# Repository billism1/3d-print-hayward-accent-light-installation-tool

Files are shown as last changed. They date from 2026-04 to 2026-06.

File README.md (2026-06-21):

# 3D-Printed Accent Light Installation & Removal Tool: Compatible with Hayward® ColorLogic® 160 / 320

> **Disclaimer:** Independent, non-commercial project. **Not affiliated with, authorized, sponsored, or endorsed by Hayward Industries, Inc.** The names "Hayward," "ColorLogic," and "SP0536CTOOL" are used only to identify the products this tool is compatible with (nominative fair use). Hayward® and ColorLogic® are trademarks of Hayward Industries, Inc.; all trademarks are the property of their respective owners.

An independently designed, 3D-printable tool that is a **compatible alternative to** the **SP0536CTOOL**, the manufacturer's installation and removal tool for **Hayward® ColorLogic® 160 and 320 accent lights**. The design was created by measuring my own light fixture, not from any manufacturer drawings or CAD.

📦 **[View, download, or print on MakerWorld](https://makerworld.com/en/models/2957577-hayward-colorlogic-light-install-removal-tool)**

## Why This Exists

The original SP0536CTOOL broke during a light removal in my pool, and I didn't want to wait for a replacement. Rather than being stuck, I designed and printed my own version. Nothing here is for sale. This repo contains the OpenSCAD source files and ready-to-print exports, shared for reference.

## The Finished Tool

### Finished Hand Tool (Separated Prongs, Epoxied)

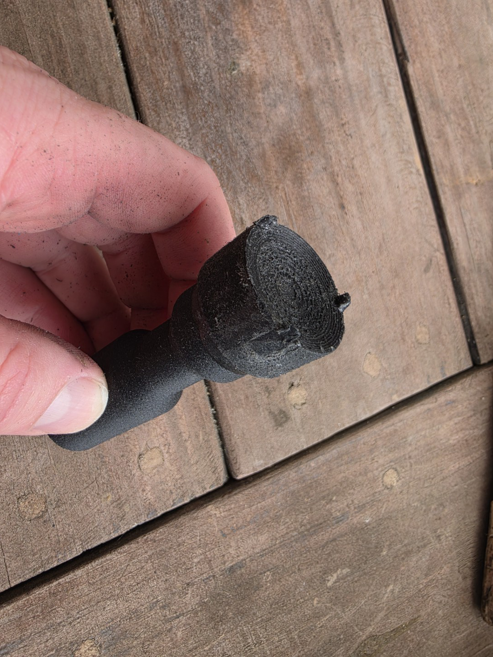
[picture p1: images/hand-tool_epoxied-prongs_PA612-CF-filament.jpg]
Hand tool with epoxied prongs — Fiberon PA612-CF


The final working version of the hand tool, printed in **Fiberon PA612-CF** nylon carbon fiber filament. The prongs were printed separately with layer lines running lengthwise, then epoxied into the designed slots on the end piece and left to cure overnight. This is the version that successfully survived the ColorLogic module replacement.

### 3D Printed Grip Collar

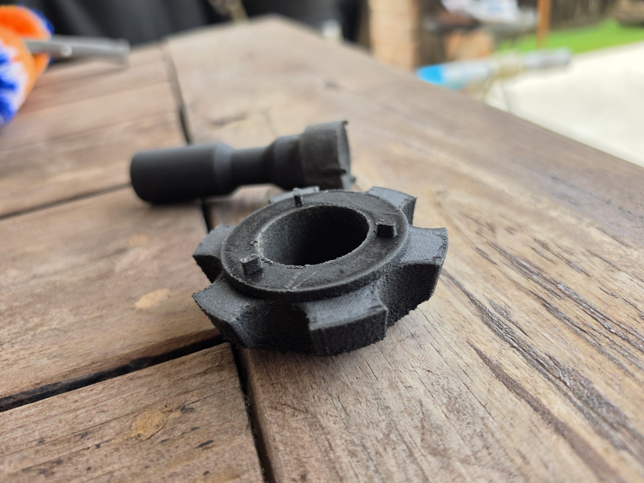
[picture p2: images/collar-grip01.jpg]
3D printed grip collar


The grip collar printed and in hand. Six gear-like teeth with semicircular cutouts give a positive grip for applying twist, and the tilted arced prongs on the top ledge engage the light's outer ring slots.

### Hand Tool in 3D Printed Collar Grip

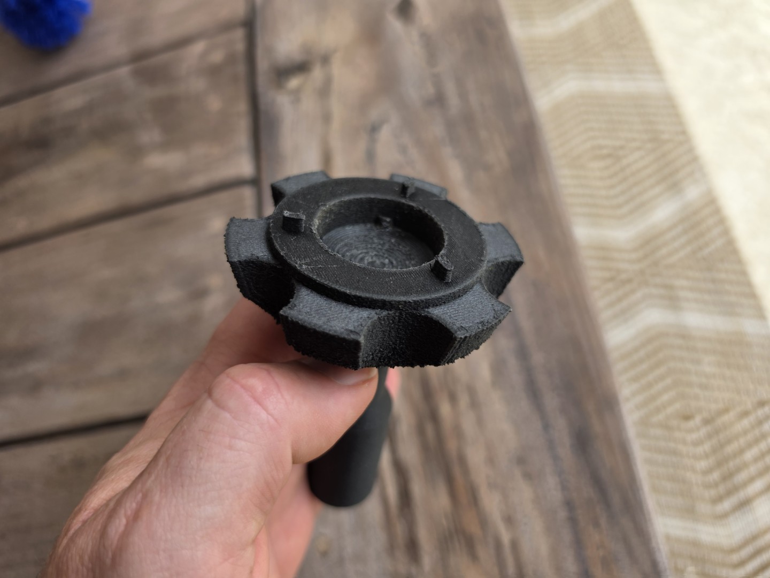
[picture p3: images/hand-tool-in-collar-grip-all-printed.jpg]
Hand tool seated in 3D printed collar grip


The fully 3D-printed assembly — the printed hand tool end piece seated inside the **printed grip collar** (both in Fiberon PA612-CF). This is the all-printed counterpart to the manufacturer-collar photo below, confirming the printed collar mates with the handle and end piece.

### 3D Printed End Piece in Manufacturer Collar Grip

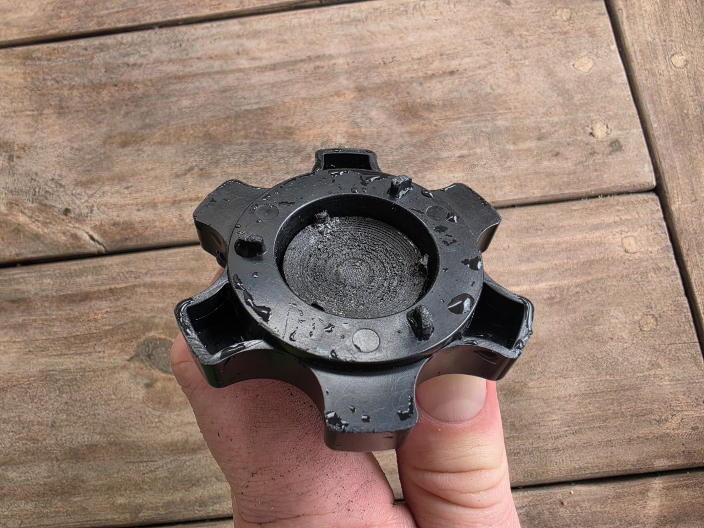
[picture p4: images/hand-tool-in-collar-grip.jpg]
Hand tool end piece seated in manufacturer collar grip


The 3D-printed end piece (printed in **Fiberon PA612-CF** filament) seated inside the **original manufacturer-supplied collar grip**, demonstrating compatibility. Since the OEM collar didn't break during use, only the handle and end piece needed to be reprinted.

## How the Tool Works

The Hayward ColorLogic accent lights mount into standard wall fittings (such as the **SP0537** or **SP0538**) using a **compression fitting**. The tool engages the light's outer ring and twists to expand or release the mounting ring inside the wall fitting.

The tool operates in two steps:

1. **Engagement** — The tool's end piece has a set of prongs ("little legs") that align with corresponding pins on the light's outer ring.
2. **Locking/Unlocking** — By twisting the tool, you rotate a fitting that compresses an internal washer. This causes the mounting ring to expand (or contract) and lock securely into (or release from) the wall fitting.

The tool consists of two main components: the **handle** (with an interlocking end piece) and the **grip collar**.

## Light Module Reference

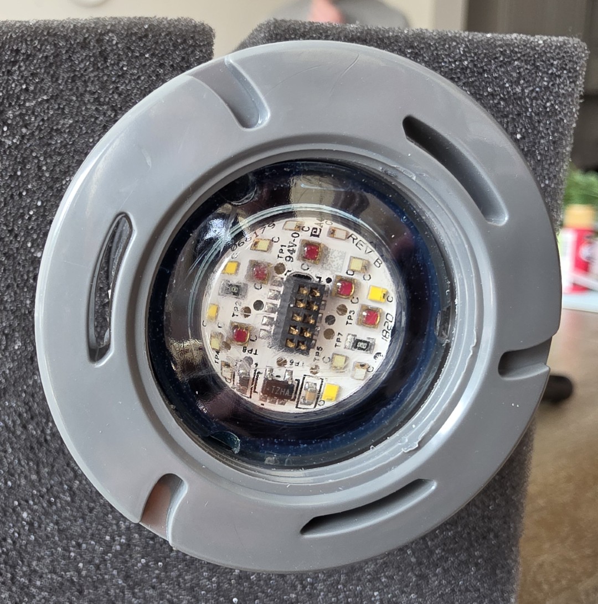
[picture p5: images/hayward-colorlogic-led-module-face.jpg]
Hayward ColorLogic LED module face


The face of a Hayward ColorLogic LED accent light module. The light has two concentric parts that the tool engages — the clear glass lens dome in the center (covering the LED board) and the gray plastic mounting ring around it. Two sets of slots are used:

- **Glass lens notches (3×)** — Cut into the clear glass lens dome surrounding the LED board, not the gray ring. The tool's end piece sits over the convex lens and its three prongs drop into these notches.
- **Gray ring slots (3×, short curved)** — Located on the outer gray mounting ring, these short curved slots are where the **grip collar prongs** engage. The collar sits over the gray ring and its tilted arced prongs seat into these slots to provide the twist leverage for locking/unlocking the light.

## Design Renders

### Handle with End Piece (Standard — Integrated Prongs)

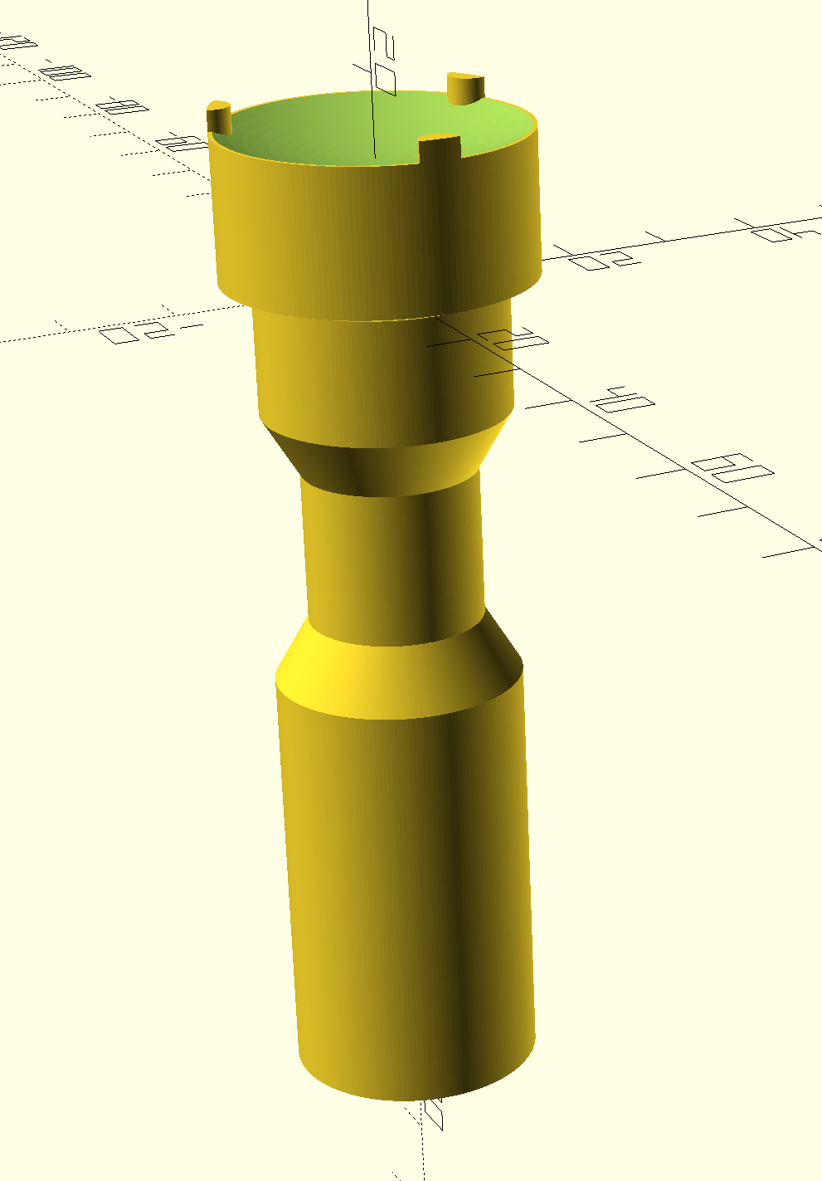
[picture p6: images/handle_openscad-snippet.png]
Handle with end piece — standard model


The handle and end piece shown as a single assembly. The concave dish on top cradles the light fixture, and three integrated prongs extend from the disc edge to engage the light's outer ring. The handle features a narrowed neck section for ergonomic grip.

### Handle with End Piece (Separate Components)

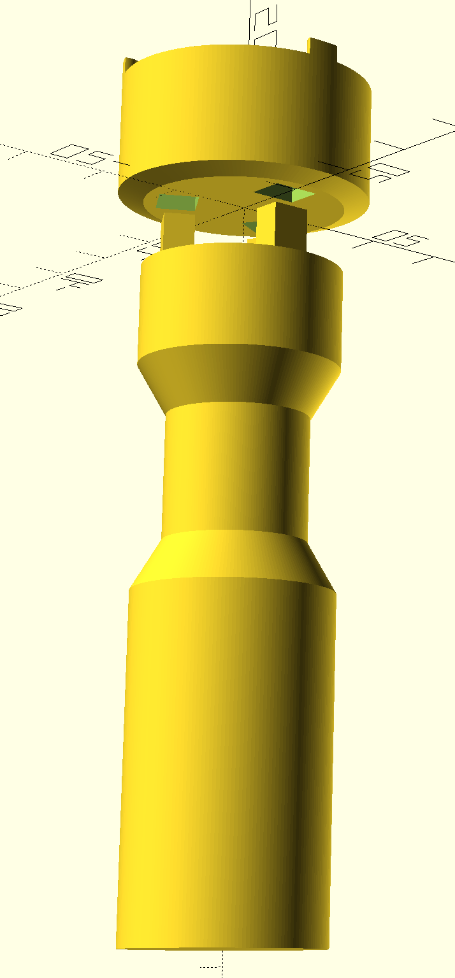
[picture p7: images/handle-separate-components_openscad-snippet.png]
Handle and end piece — separate components


The handle and end piece shown as separate printable parts. The interlocking tab system between the handle top and the disc underside is visible. The prongs here are still integrated into the end piece.

### Handle with End Piece (Separated Prongs Variant)

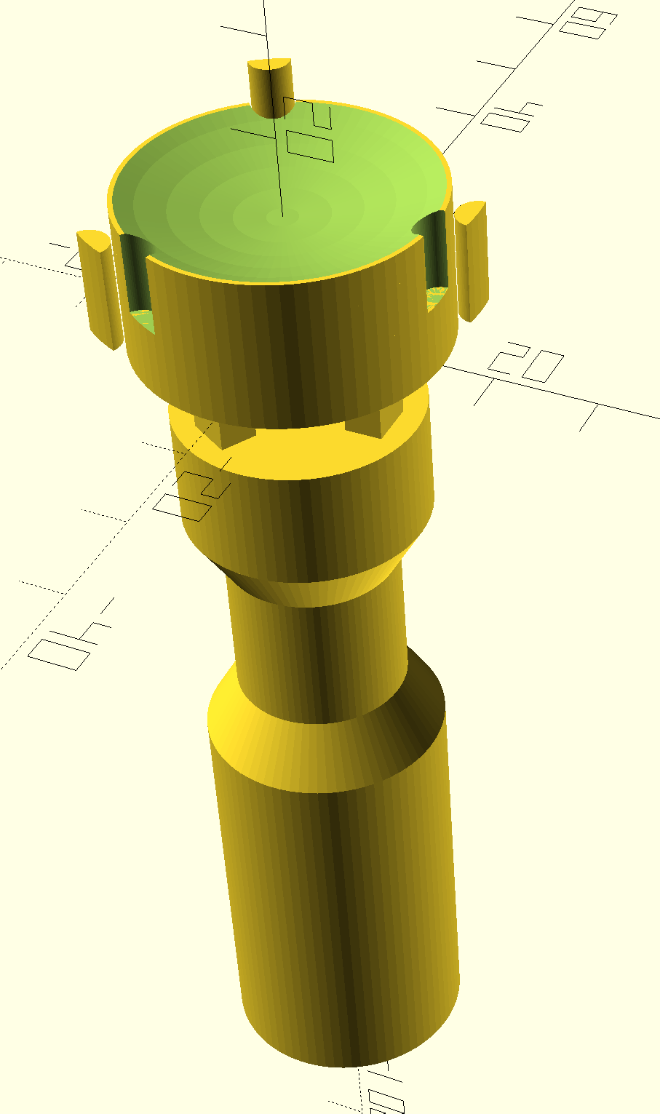
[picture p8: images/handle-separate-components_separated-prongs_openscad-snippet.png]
Handle and end piece — separated prongs variant


The improved separated prongs design. The end piece has three prong slots cut into it, and the individual prongs are printed separately alongside. This allows the prongs to be printed with layer lines running along their length for maximum inter-layer tensile strength, then epoxied into the slots.

### Grip Collar

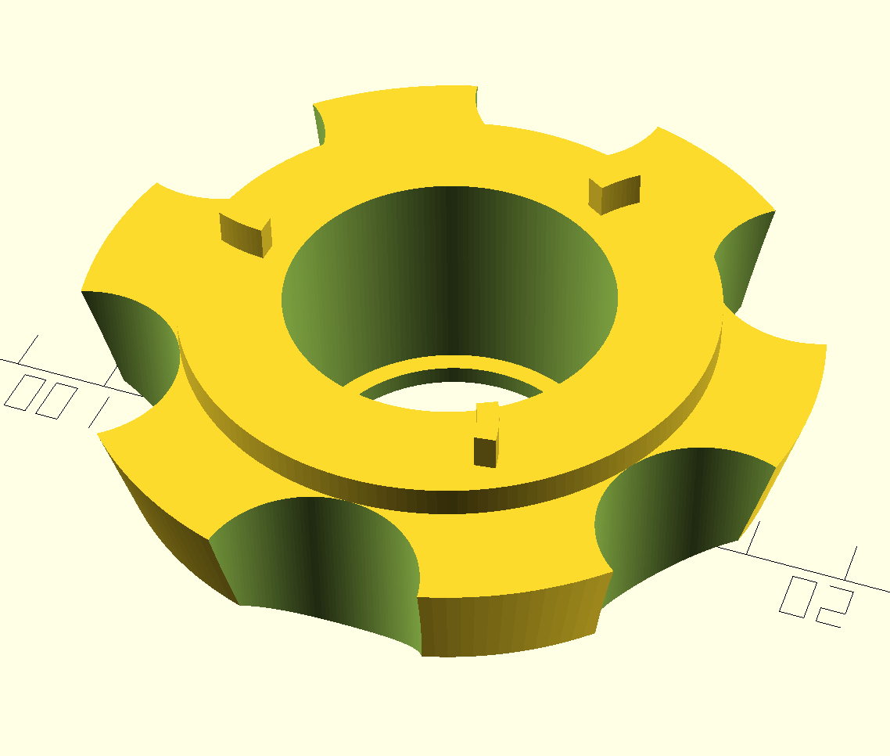
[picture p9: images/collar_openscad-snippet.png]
Grip collar


The grip collar viewed from above. Features six gear-like teeth with semicircular cutouts for hand grip, a prong ledge ring on top with three tilted arced prongs, and a retention lip on the bottom inside edge.

## Design Variants

### Standard Model (`hayward-accent-light-installation-tool.scad`)

The original design where the prongs are printed as part of the end piece. This is a simpler assembly but suffers from a critical weakness — the prongs are prone to snapping off due to weak **inter-layer tensile strength**. Because the prongs are small features extending from the disc, FDM layer lines run perpendicular to the prong length. Forces during installation/removal try to pull layers apart (delamination), which is the weakest failure mode in FDM printing.

### Separated Prongs Model (`hayward-accent-light-installation-tool_prongs-separated.scad`)

An improved design where the prongs are **printed as separate pieces** with layer lines running along their length (longitudinally). This orients the strong axis of each layer in the direction of load, dramatically improving **inter-layer tensile strength** and resistance to delamination. The prongs are then bonded into slots in the end piece with **epoxy** (cured overnight). Some light sanding of excess epoxy may be needed after curing.

## Printing Experience & Material Testing

All prints were done on a **Bambu Lab P1S**.

| Attempt | Model | Filament | Result |
|---|---|---|---|
| 1 | Standard (integrated prongs) | ASA (similar to ABS) | **Failed** — prongs snapped off very easily |
| 2 | Standard (integrated prongs) | Nylon Carbon Fiber (**Fiberon PA612-CF**) | Significantly stronger, but still managed to break a prong during use |
| 3 | Separated prongs | Fiberon PA612-CF + epoxy assembly | **Success** — prongs oriented with layer lines lengthwise held up to the torque required for light installation/removal |

### Key Takeaway

Printing small structural features like prongs **separately** and orienting them so that layer lines run parallel to the load direction provides far superior strength compared to printing them in-place. Even a high-performance filament like Nylon CF couldn't overcome the inherent inter-layer weakness of FDM when the prongs were printed as part of the larger piece.

## Assembly Notes (Separated Prongs Model)

1. Print the end piece and individual prongs separately.
2. Apply epoxy to the prong slots and insert the prongs.
3. Allow the epoxy to cure overnight.
4. Sand off any excess epoxy.

## TODO

- [ ] **Grip collar: separated prongs variant** — The grip collar also has prongs on its ledge that could benefit from the same separated-prong treatment for added strength. I didn't break the collar during my testing (only the end piece prongs failed), so this variant hasn't been designed yet. It is likely needed for long-term durability.

## Repository Structure

```
src/
  hayward-accent-light-installation-tool.scad              # Standard model (handle, end piece, grip collar)
  hayward-accent-light-installation-tool_prongs-separated.scad  # Separated prongs variant (end piece + handle)

publication/
  hayward-accent-light-installation-tool.3mf               # Bambu Lab 3MF project file
  hayward-accent-light-installation-tool_collar.stl         # Grip collar
  hayward-accent-light-installation-tool_end.stl            # End piece (standard, integrated prongs)
  hayward-accent-light-installation-tool_end_prong.stl      # Individual prong for separated model
  hayward-accent-light-installation-tool_end_with_prong_slots.stl  # End piece with prong slots
  hayward-accent-light-installation-tool_handle.stl         # Handle
  hayward-accent-light-installation-tool_handle_short.stl   # Short handle variant
  hayward-accent-light-installation-tool_one_peice.stl      # One-piece combined end piece + handle
```

## Compatible Lights & Fittings

- **Lights:** Hayward ColorLogic 160, ColorLogic 320 accent lights
- **Wall Fittings:** Hayward SP0537, SP0538 (1.5" female pipe thread)
- **OEM Tool:** Hayward SP0536CTOOL

## License

This is a personal project shared for reference under the [MIT License](LICENSE). Use at your own risk. Pool equipment installation involves water-tight seals and electrical components, so verify fit and function before relying on a 3D-printed tool for permanent installations.

See [LICENSE](LICENSE) for the full trademark notice and liability disclaimer.

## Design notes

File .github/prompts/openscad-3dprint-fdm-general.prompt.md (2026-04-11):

# OpenSCAD – General FDM 3D Printing Prompt

> Use this prompt for any OpenSCAD work targeting FDM (Fused Deposition Modelling) printers.

## Language Notes

OpenSCAD is a **functional CSG modelling language**, not a general-purpose programming language.

Key differences from typical languages:
- **No mutable variables** — all values are computed at parse time
- **No loops with side effects** — use `for()` as a geometric generator, not a control flow loop
- **Modules produce geometry**, not return values
- **`difference()`, `union()`, `intersection()`** are the core boolean CSG operations
- **`hull()`** creates the convex hull of its children — commonly used for fillets and smooth transitions
- **`translate()`, `rotate()`, `scale()`** are transforms applied to children
- **`$fn`** controls facet count (smoothness of curves)
- **`children()`** lets a module operate on geometry passed to it
- **`let()`** introduces named intermediate values inside expressions
- **`each`** flattens nested lists in list comprehensions

## FDM Design Principles

### Orientation matters
- The **flat, largest face should sit on the build plate** whenever possible.
- Minimise the need for support material by avoiding large unsupported overhangs.
- Vertical cylindrical holes print well; horizontal ones may need tear-drop or bridging profiles.

### Strength considerations
- **Layer lines are weakest in tension along Z.** Design load-bearing features so forces act across (XY) rather than between layers.
- Add fillets at the base of vertical features to distribute stress and reduce stress-risers.
- Prefer rounded transitions over sharp internal corners to avoid stress concentration.

### Printability guidelines
- Avoid very thin walls (< 2 × nozzle diameter). Typical minimum wall thickness: **0.8–1.2 mm** for a 0.4 mm nozzle.
- Bridging spans should stay under **~50 mm** without support.
- Overhangs up to **~45°** from vertical generally print without support; steeper angles may need chamfers or supports.
- Design snap-fits and living hinges with grain direction (layer orientation) in mind.

## Common Patterns

### Rounded rectangle (cube with round XY edges)
```openscad
module rounded_rect(size, r) {
    hull() {
        for (x = [r, size.x - r], y = [r, size.y - r])
            translate([x, y, 0])
                cylinder(r = r, h = size.z);
    }
}
```

### Fillet at base of a vertical feature
```openscad
module base_fillet(r, h) {
    difference() {
        cube([r, r, h]);
        translate([r, r, -0.01])
            cylinder(r = r, h = h + 0.02);
    }
}
```

### Chamfered hole (countersink / printer-friendly top)
```openscad
module chamfered_hole(d, h, chamfer = 0.6) {
    union() {
        cylinder(d = d, h = h);
        translate([0, 0, h - chamfer])
            cylinder(d1 = d, d2 = d + 2 * chamfer, h = chamfer + 0.01);
    }
}
```

### Shell / hollow box
```openscad
module shell(outer, wall) {
    difference() {
        cube(outer);
        translate([wall, wall, wall])
            cube([outer.x - 2*wall, outer.y - 2*wall, outer.z]);
    }
}
```

### Slot (elongated hole)
```openscad
module slot(length, d, h) {
    hull() {
        cylinder(d = d, h = h);
        translate([length, 0, 0])
            cylinder(d = d, h = h);
    }
}
```

### Counterbore hole
```openscad
module counterbore_hole(d_through, d_head, h_total, h_head) {
    union() {
        cylinder(d = d_through, h = h_total + 0.01);
        translate([0, 0, h_total - h_head])
            cylinder(d = d_head, h = h_head + 0.01);
    }
}
```

### Text / label emboss or deboss
```openscad
// Debossed (engraved) text on top surface
module debossed_label(txt, size, depth, font = "Liberation Sans:style=Bold") {
    translate([0, 0, -depth])
        linear_extrude(depth + 0.01)
            text(txt, size = size, font = font, halign = "center", valign = "center");
}
```

### Circular pattern (polar array)
```openscad
module polar_array(n, r) {
    for (i = [0 : n - 1])
        rotate([0, 0, i * 360 / n])
            translate([r, 0, 0])
                children();
}
```

## Tolerances for FDM 3D Printing

| Fit Type | Tolerance | Example |
|---|---|---|
| Press-fit (tight interference) | +0.1–0.2 mm on ID | `insert_od + 0.15` |
| Snug / sliding fit | +0.2–0.4 mm | `shaft_d + 0.3` |
| Loose / clearance fit | +0.5–1.0 mm | `cable_d + 0.6` |
| Screw through-hole | +0.3–0.5 mm | `M4 → 4.4 mm hole` |
| Self-threading (screw into plastic) | ~85% of nominal | `M4 → 3.4 mm hole` |
| Mating flat surfaces (stacking) | +0.2 mm per axis | offset to prevent binding |
| Lid / cap fit | +0.3–0.5 mm radial clearance | on diameter |

## Recommended `$fn` Values

| Feature | `$fn` | Notes |
|---|---|---|
| Small holes (< 6 mm) | 24–32 | Keeps file size small, holes still round |
| Medium cylinders (6–30 mm) | 48–64 | Good visual smoothness |
| Large curves / decorative | 96–128 | For visible surfaces |
| Hex shapes | 6 | `cylinder(..., $fn=6)` gives a hexagon |
| Quick preview / development | 16–24 | Faster render while iterating |
| Final export | 64–128 | Use higher values for production STL |

## CSG Best Practices

- Always extend cut volumes by **0.01 mm** (epsilon) beyond the surface to avoid z-fighting / coincident faces.
- Keep geometry **manifold** — no zero-thickness walls, no self-intersecting volumes.
- Use `render()` sparingly; it forces CGAL evaluation and slows preview.
- Name modules descriptively (e.g., `mounting_tab()`, `drain_slot()`) and parametrise dimensions at the top of the file.
- Group related constants together and comment units: `wall = 2.5; // mm`.
- Use `assert()` to guard against invalid parameter combinations.

## File Organisation

```
// 1. Constants & parameters
// 2. Derived dimensions
// 3. Helper / utility modules
// 4. Component modules
// 5. Assembly (top-level geometry)
```

Keep the top-level geometry at the **bottom** of the file so that reading top-to-bottom flows from parameters → helpers → final shape.

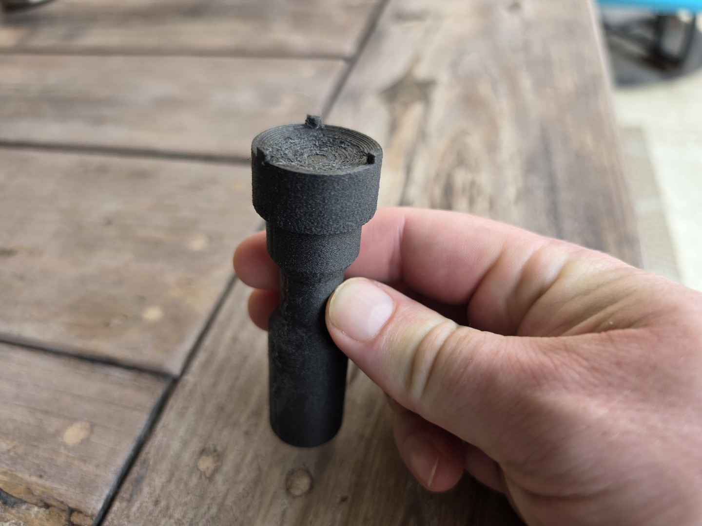
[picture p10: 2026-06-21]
images/hand-tool_integrated-prongs_PA612-CF-filament.jpg

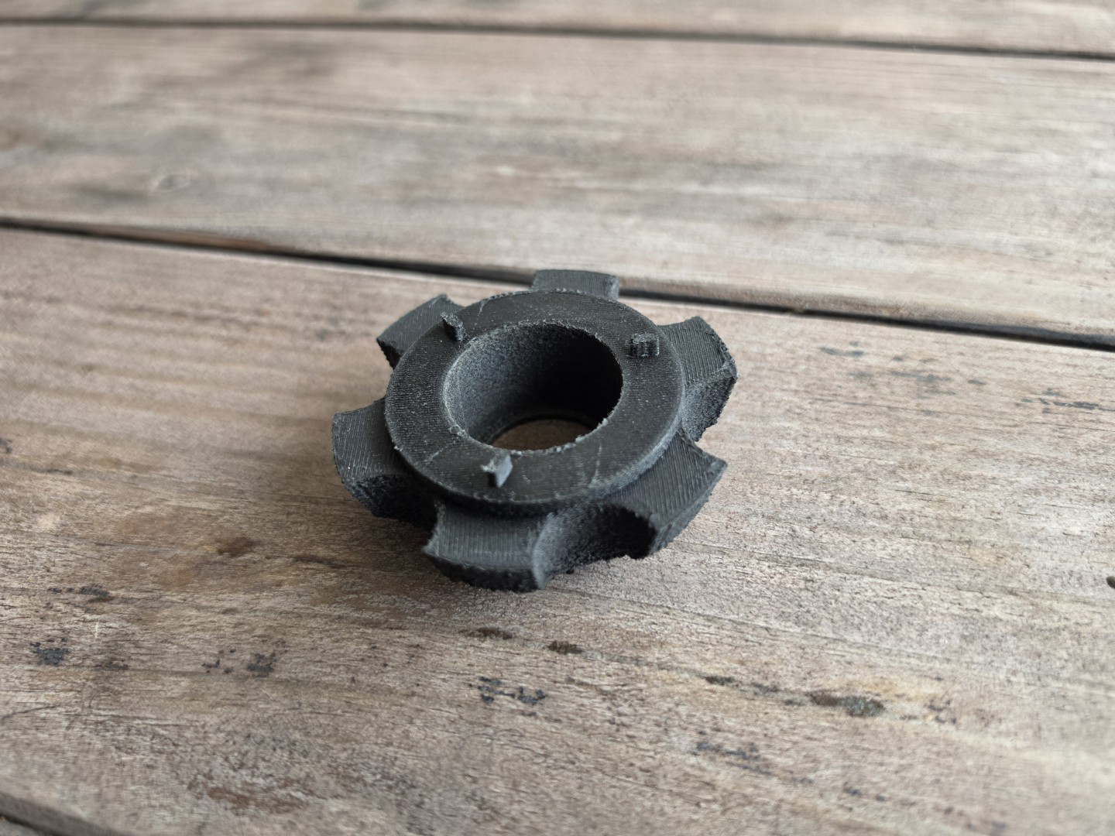
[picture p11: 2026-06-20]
images/collar-grip02.jpg

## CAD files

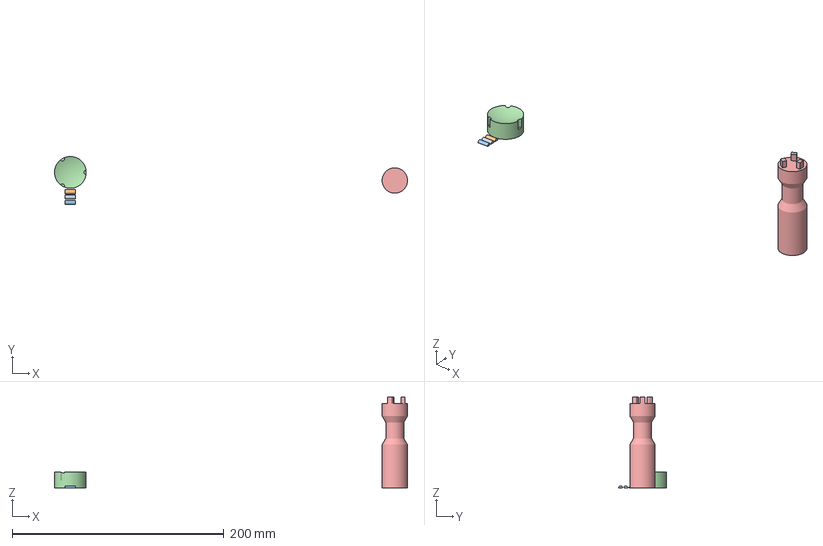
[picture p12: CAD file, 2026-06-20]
publication/hayward-accent-light-installation-tool_separated-prongs.3mf
333.8 x 45.4 x 86.0 mm
hayward-accent-light-installation-tool_end_prong.stl x 3
hayward-accent-light-installation-tool_end_with_prong_slots.stl
hayward-accent-light-installation-tool_handle.stl

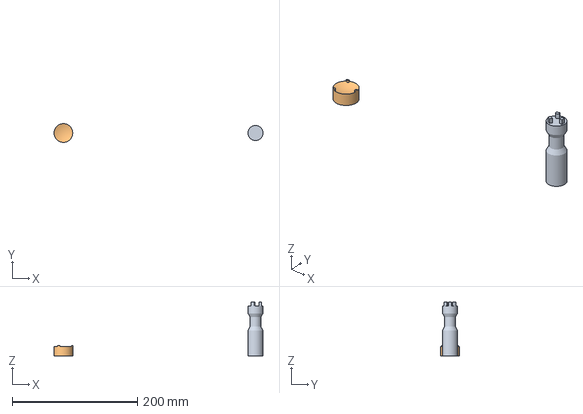
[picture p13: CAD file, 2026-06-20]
publication/hayward-accent-light-installation-tool_integrated-prongs.3mf
334.2 x 30.0 x 86.0 mm
hayward-accent-light-installation-tool_handle.stl
hayward-accent-light-installation-tool_end.stl

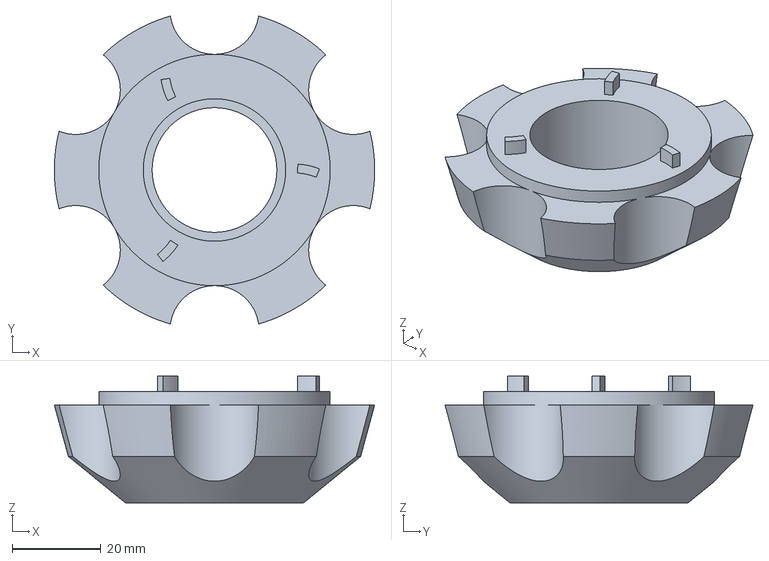
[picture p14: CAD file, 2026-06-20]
publication/hayward-accent-light-installation-tool_collar-grip.3mf
72.0 x 69.2 x 28.5 mm

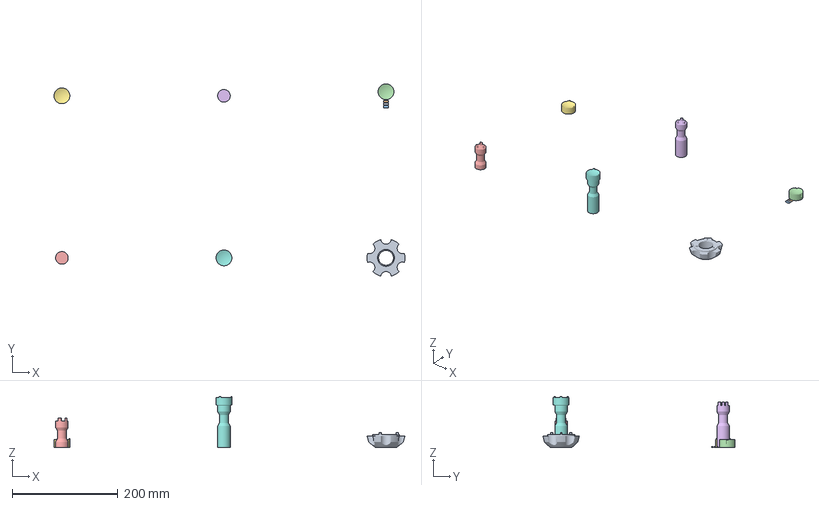
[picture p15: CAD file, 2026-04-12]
publication/hayward-accent-light-installation-tool.3mf
665.4 x 364.5 x 97.0 mm
hayward-accent-light-installation-tool_end_prong.stl x 3
hayward-accent-light-installation-tool_end_with_prong_slots.stl
hayward-accent-light-installation-tool_handle_short.stl
hayward-accent-light-installation-tool_handle.stl
hayward-accent-light-installation-tool_end.stl
hayward-accent-light-installation-tool_one_peice.stl
hayward-accent-light-installation-tool_collar.stl

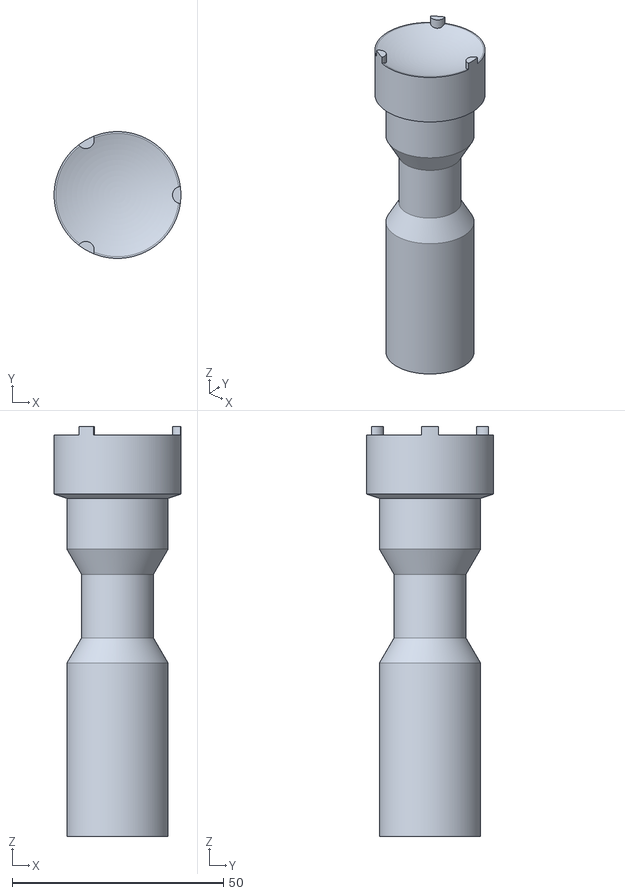
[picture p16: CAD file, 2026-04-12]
publication/hayward-accent-light-installation-tool_one_peice.stl
30.0 x 30.0 x 97.0

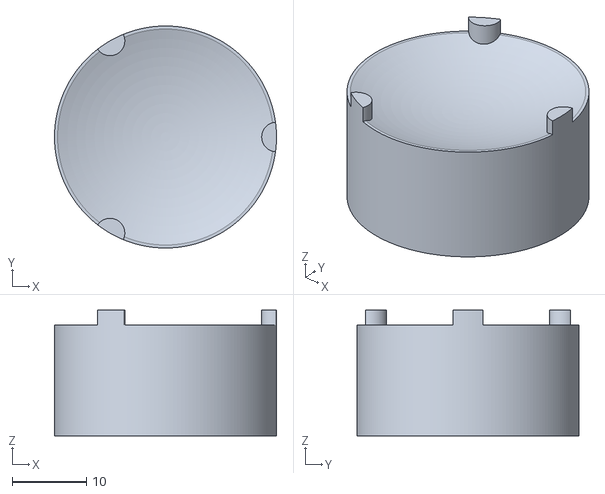
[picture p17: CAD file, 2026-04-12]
publication/hayward-accent-light-installation-tool_end.stl
30.0 x 30.0 x 17.0

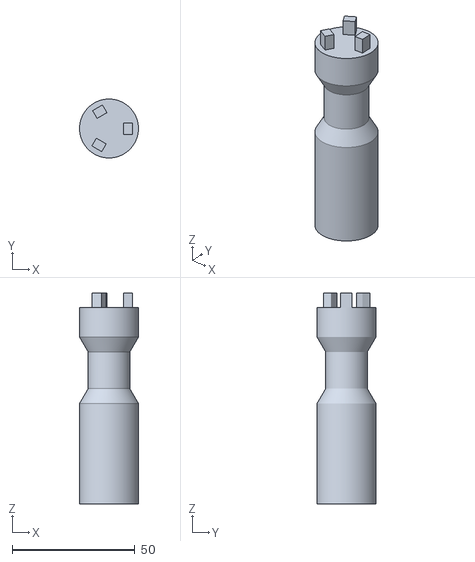
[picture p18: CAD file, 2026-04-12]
publication/hayward-accent-light-installation-tool_handle.stl
24.0 x 24.0 x 86.0

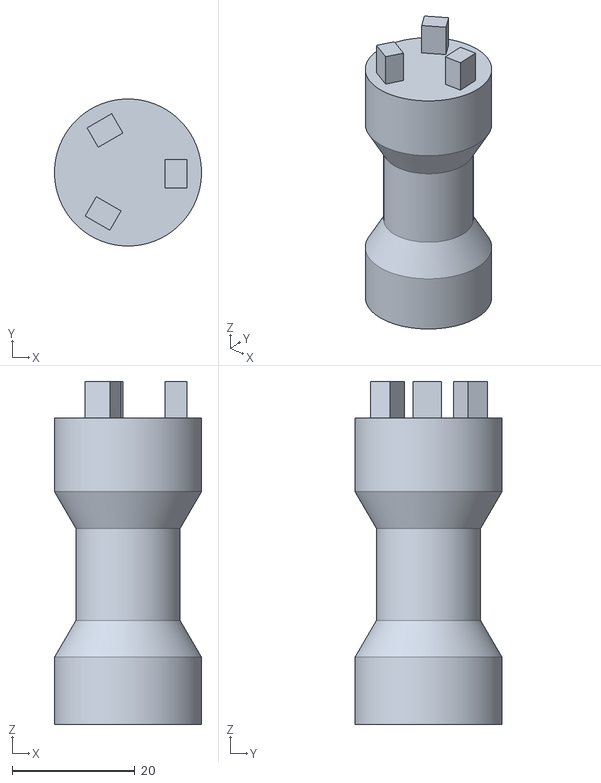
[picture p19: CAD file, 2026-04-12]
publication/hayward-accent-light-installation-tool_handle_short.stl
24.0 x 24.0 x 56.0

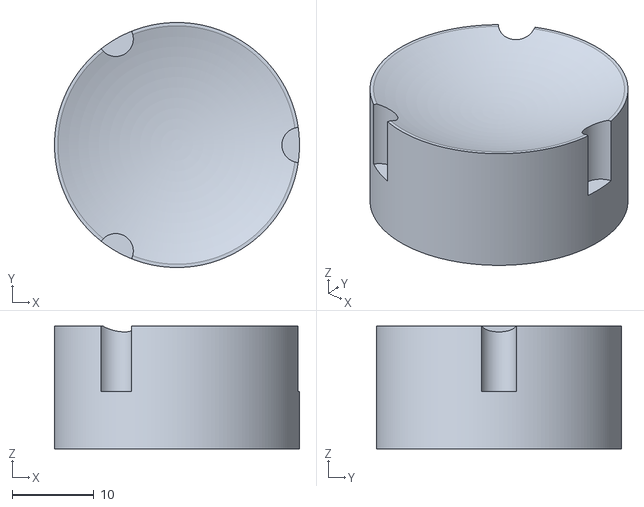
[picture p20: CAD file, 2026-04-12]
publication/hayward-accent-light-installation-tool_end_with_prong_slots.stl
30.0 x 30.0 x 15.0

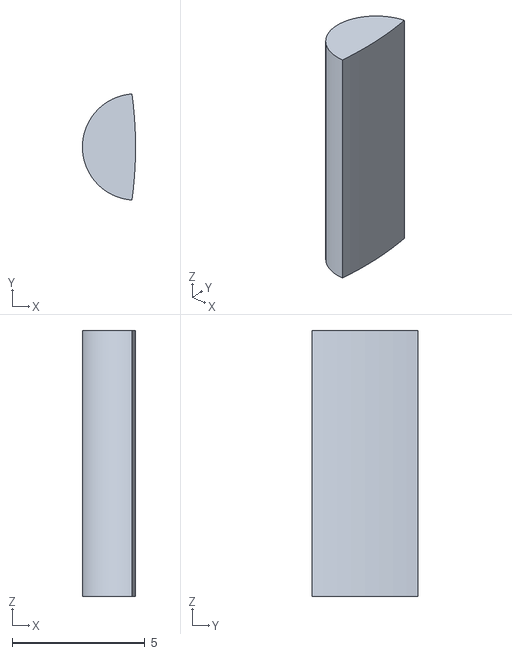
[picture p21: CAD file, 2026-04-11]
publication/hayward-accent-light-installation-tool_end_prong.stl
2.00 x 3.99 x 10.0

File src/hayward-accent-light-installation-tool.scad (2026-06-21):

// ============================================================
// Accent Light Installation Tool (End Piece), compatible with Hayward ColorLogic 160/320
// Independent, non-commercial project. Not affiliated with Hayward Industries, Inc.
// ============================================================

// ----- Constants & Parameters -----
disc_diameter   = 30;     // mm – outer diameter of the circular end
disc_thickness  = 15;     // mm – depth (Z) of the flat disc

prong_height    = 2;      // mm – how far prongs extend above the disc
prong_arc_len   = 4;    // mm – arc length of each prong along circumference
prong_count     = 3;

// Concave dish on top of disc (to cradle convex light fixture)
dish_depth      = 3;      // mm – how deep the concavity is

// Render toggles
render_end_piece  = true;
render_handle     = true;
render_grip_collar = true;
render_combined   = false;  // true = union end piece + handle as one solid object

// Handle parameters
handle_diameter = 24;     // mm
handle_length   = 80;     // mm
handle_gap      = 2;      // mm – visual gap between handle and disc

// Handle neck parameters
neck_start      = 12;     // mm – distance from top of handle to start of neck
neck_diameter   = 17;     // mm – narrowed diameter
neck_length     = 15;     // mm – length of the narrow section
neck_taper      = 6;      // mm – length of each conical transition

// Grip collar parameters
collar_inner_diameter  = 32;     // mm – inside diameter (end piece sits inside)
collar_base_thickness  = 10;     // mm – base ring wall thickness at top
collar_base_thickness_bottom = 4; // mm – base ring wall thickness at bottom
collar_tooth_thickness = 10;     // mm – additional thickness for gear-tooth region
collar_height          = 22;     // mm – height when printed flat on bed
collar_tooth_count     = 6;      // number of gear-like grip teeth
collar_ledge_width     = 10;     // mm – radial width of the prong ledge ring on top
collar_ledge_height    = 3;      // mm – height the ledge extrudes above the collar
collar_tooth_taper_h   = 13;     // mm – height of 45° taper on bottom of teeth (= tooth thickness)

// Collar lip parameters (retention lip on bottom inside)
collar_lip_height      = 2;      // mm – height of the lip
collar_lip_thickness   = 2;      // mm – radial extent inward from inner diameter

// Collar prong parameters
collar_prong_height    = 3.5;    // mm – height of prongs above the ledge
collar_prong_thickness = 2;    // mm – wall thickness of each prong arc
collar_prong_count     = 3;      // number of prongs, evenly spaced
collar_prong_ring_od   = 30;     // mm – outer diameter of the hypothetical ring defining arc curvature
collar_prong_length    = 5;      // mm – radial length of each prong arc
collar_prong_tilt      = 12.5;     // degrees – clockwise tilt (outer end leads CW viewed from top)

// Interlocking tab parameters
tab_count       = 3;
tab_width       = 5;      // mm – width tangentially
tab_depth       = 4;      // mm – radial depth of each tab
tab_height      = 6;      // mm – how far tabs protrude into the disc
tab_radial_pos  = 8;      // mm – distance from center to tab center
tab_clearance   = render_combined ? 0.0 : 0.35;   // mm – press-fit tolerance per side (0 when combined)

// ----- Derived Dimensions -----
disc_radius     = disc_diameter / 2;
handle_radius   = handle_diameter / 2;
prong_arc_angle = (prong_arc_len / (PI * disc_diameter)) * 360; // degrees
eps             = 0.01;   // mm – tiny overlap to avoid z-fighting

// Slot dimensions (tab + clearance on each side)
slot_width      = tab_width + 2 * tab_clearance;
slot_depth      = tab_depth + 2 * tab_clearance;

// Grip collar derived dimensions
collar_inner_radius = collar_inner_diameter / 2;
collar_total_thickness = collar_base_thickness + collar_tooth_thickness;
collar_outer_radius = collar_inner_radius + collar_total_thickness;  // full outer radius including teeth
collar_base_outer_radius = collar_inner_radius + collar_base_thickness; // outer radius of base ring at top
collar_base_outer_radius_bottom = collar_inner_radius + collar_base_thickness_bottom; // outer radius of base ring at bottom
collar_outer_radius_bottom = collar_base_outer_radius_bottom + collar_tooth_thickness; // full outer radius at bottom
collar_cutout_radius = collar_tooth_thickness;  // radius of each semicircular cutout

// Collar prong derived dimensions
collar_prong_ring_or = collar_prong_ring_od / 2;
collar_prong_ring_ir = collar_prong_ring_or - collar_prong_thickness;
// Radial center of the ledge, where prongs sit
collar_prong_center_r = collar_inner_radius + collar_ledge_width / 2;
// Arc angle derived from the hypothetical ring curvature and desired prong length
collar_prong_arc_deg = (collar_prong_length / collar_prong_ring_or) * (180 / PI);

// ----- Quality -----
$fn = 80;

// ----- Component Modules -----

disc_taper_height = 1;    // mm – height of conical taper at bottom of disc

module disc() {
    // Bottom cone: tapers from handle_diameter up to disc_diameter
    cylinder(d1 = handle_diameter, d2 = disc_diameter, h = disc_taper_height);
    // Remaining straight cylinder
    translate([0, 0, disc_taper_height])
        cylinder(d = disc_diameter, h = disc_thickness - disc_taper_height);
}

module prong() {
    prong_total_h = prong_height + dish_depth + eps;
    half_arc = prong_arc_len / 2;

    // Lens shape from above: outer follows disc curvature, inner is convex toward center
    intersection() {
        // Cylinder centered on disc edge along +X
        translate([disc_radius, 0, 0])
            cylinder(r = half_arc, h = prong_total_h);
        // Clip to inside the disc radius
        cylinder(r = disc_radius, h = prong_total_h);
    }
}

module prongs() {
    for (i = [0 : prong_count - 1])
        rotate([0, 0, i * (360 / prong_count)])
            translate([0, 0, disc_thickness - dish_depth - eps])
                prong();
}

// Cutout slots in the bottom of the disc for the handle tabs
module disc_slots() {
    for (i = [0 : tab_count - 1])
        rotate([0, 0, i * (360 / tab_count)])
            translate([tab_radial_pos - slot_depth / 2,
                       -slot_width / 2,
                       -eps])
                cube([slot_depth, slot_width, tab_height + eps]);
}

// Spherical concave dish cut from the top of the disc
module dish_cutout() {
    // Sphere radius derived so that a cap of dish_depth has the disc's radius as chord
    dish_r = (disc_radius * disc_radius + dish_depth * dish_depth) / (2 * dish_depth) - 2;
    translate([0, 0, disc_thickness - dish_depth + dish_r])
        sphere(r = dish_r);
}

// The disc with slots and concave dish cut out
module end_piece() {
    difference() {
        disc();
        disc_slots();
        dish_cutout();
    }
    prongs();
}

// Tabs that protrude from the top of the handle
module handle_tabs() {
    for (i = [0 : tab_count - 1])
        rotate([0, 0, i * (360 / tab_count)])
            translate([tab_radial_pos - tab_depth / 2,
                       -tab_width / 2,
                       handle_length])
                cube([tab_depth - tab_clearance, tab_width - tab_clearance, tab_height]);
}

module handle() {
    neck_bottom = handle_length - neck_start - neck_taper - neck_length - neck_taper;
    // Top section: full diameter
    translate([0, 0, handle_length - neck_start])
        cylinder(d = handle_diameter, h = neck_start);
    // Upper taper: handle_diameter -> neck_diameter
    translate([0, 0, handle_length - neck_start - neck_taper])
        cylinder(d1 = neck_diameter, d2 = handle_diameter, h = neck_taper);
    // Narrow neck section
    translate([0, 0, handle_length - neck_start - neck_taper - neck_length])
        cylinder(d = neck_diameter, h = neck_length);
    // Lower taper: handle_diameter -> neck_diameter
    translate([0, 0, neck_bottom])
        cylinder(d1 = handle_diameter, d2 = neck_diameter, h = neck_taper);
    // Bottom section: full diameter
    cylinder(d = handle_diameter, h = neck_bottom);
    handle_tabs();
}

// ----- Grip Collar Module -----
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

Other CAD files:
publication/hayward-accent-light-installation-tool_collar.stl
src/hayward-accent-light-installation-tool_prongs-separated.scad

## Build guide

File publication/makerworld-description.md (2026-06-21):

# 3D-Printed Accent Light Installation & Removal Tool: Compatible with Hayward ColorLogic

An independently designed 3D-printable alternative, compatible with the Hayward ColorLogic light system (replaces the function of the SP0536CTOOL).

> **Disclaimer:** Independent, non-commercial project. **Not affiliated with, authorized, sponsored, or endorsed by Hayward Industries, Inc.** The names "Hayward," "ColorLogic," and "SP0536CTOOL" are used only to identify the products this tool is compatible with (nominative fair use). Hayward® and ColorLogic® are trademarks of Hayward Industries, Inc.; all trademarks are the property of their respective owners.

> **Source & Documentation:** OpenSCAD source, photos, and full documentation: [github.com/billism1/3d-print-hayward-accent-light-installation-tool](https://github.com/billism1/3d-print-hayward-accent-light-installation-tool)

Yeah, so the manufacturer's tool for replacing ColorLogic accent lights broke mid-removal, with the light still in the wall. Could have ordered another one and waited. Instead I broke a few prototypes, reinforcing what I already know about FDM layer orientation: it actually matters for small pieces, and ended up with a tool that survived the job. I designed this from measuring my own light, not from any manufacturer drawings. Three print profiles below: two for the hand tool (pick by how much epoxy you feel like dealing with), plus a separate one for the grip collar if yours broke too. Realistically, almost nobody needs this. But if your tool broke and your light is still stuck in the wall, you are exactly the person I made it for. So hello to the few of you who stumble across this, probably years from now. Small club, glad you're here.

This is an independently designed, 3D-printable alternative to the **SP0536CTOOL**, the manufacturer's installation and removal tool for **Hayward ColorLogic 160 and 320** accent lights. Nothing here is for sale. The tool engages the light's outer ring and twists to expand or release the internal mounting ring inside a standard wall fitting (SP0537, SP0538).

## Three Print Profiles

Profiles 1 and 2 both print the **hand tool: the end piece *and* the handle**. The handle has extension pieces (tabs) that insert into matching slots in the underside of the end piece to hold the two together. I epoxied mine, but I also ran it *without* epoxying the handle to the end piece and it held up fine — the tabs alone keep them together. So epoxy on the handle joint is optional; glue it only if you want it permanent.

Profile 3 is the grip collar, broken out on its own because you may not need it. Print it only if your OEM collar didn't survive. Mine survived. I designed and printed one anyway. Two reasons: I can't leave a set half-finished, and your collar might not be as lucky as mine.

**Profile 1: Separated Prongs (Stronger, Recommended)**
The end piece prints with three prong slots. The three prongs print separately, lying flat on the bed so their layer lines run along their length. You epoxy the prongs into the slots. Stronger because the strong axis of each layer is now aligned with the torque, instead of fighting it across layer bonds. The handle prints separately and its tabs insert into the end piece (epoxy on that joint optional).

**Profile 2: Integrated Prongs (Simpler)**
The end piece prints as one part with the prongs as integrated features. Fewer pieces, no prong epoxy step, faster to assemble. The trade-off is the inter-layer weakness. Even Nylon CF couldn't fully overcome it in my testing. Fine for a one-time removal or a backup. If you just need to get the light out today, this is the fastest path. The handle still prints separately and its tabs insert into the end piece (epoxy on that joint optional).

**Profile 3: Grip Collar (Optional — Print Only If Needed, Or If You're Like Me)**
Just the grip collar, on its own. Six gear-style teeth for hand grip, a retention lip, and three tilted arced prongs that engage the outer ring slots on the light. Print this only if your OEM Hayward collar broke — the printed end piece drops into the original collar fine. My OEM collar was perfectly intact. I designed this one anyway. No regrets. Print it by itself or alongside Profile 1 or 2.

## What's Included

Long handle: separate part, epoxied to the underside of the end piece. Tab system aligns it; epoxy holds it.
End piece: two versions, one per profile (slotted vs. integrated).
Individual prong: three needed for Profile 1.
Grip collar: one piece. Skip printing it if your OEM collar survived; the 3D-printed end piece fits inside the original collar fine.

## Key Features

Designed for FDM strength. Profile 1 puts the prongs' layer lines along the load direction, where FDM is strong, instead of perpendicular, where it delaminates.
Interlocking handle joint: three tab-and-slot pairs align the handle to the end piece before you epoxy.
Concave dish on the end piece cradles the convex face of the light fixture.
Narrowed neck on the handle gives you something ergonomic to grip and twist.
Six-tooth grip collar: gear-style cutouts for hand grip, with a retention lip and three tilted arced prongs to engage the outer ring slots on the light.
OEM-compatible end piece fits inside the manufacturer-supplied collar if you only broke the handle.

## Print Tips

**Filament:** Print in something tough. My log:

Attempt 1: Integrated prongs in ASA. Prongs snapped almost immediately.
Attempt 2: Integrated prongs in **Fiberon PA612-CF** (Nylon CF). Stronger, but still broke a prong under twist torque.
Attempt 3: Separated prongs in **Fiberon PA612-CF** + epoxy. Held up to the full install/removal torque.

PLA is going to disappoint you. PETG or ABS *might* survive Profile 1. PA-CF or PA6-CF is the safer bet for either profile. All my prints were on a **Bambu Lab P1S**.

**Orientation:** The included files are already oriented for the right layer direction. The separated prongs print flat on the bed (longitudinal layer lines), and the slotted end piece prints with the dish facing up.

**Epoxy:** Two-part epoxy is fine (5-minute or slow-cure both work). Squeeze-out is normal. Wipe or sand it after cure.

## Assembly

**Profile 1 (Separated Prongs):**
1. Print the end piece (with prong slots), three prongs, and handle. Print the grip collar too (Profile 3) only if you need it.
2. Epoxy the prongs into the end piece slots. Cure overnight.
3. Insert the handle's tabs into the slots on the underside of the end piece. Epoxy here is optional — mine ran fine unglued. If gluing, cure overnight.
4. Light sand any squeeze-out.
5. Drop the end piece into the grip collar (printed or OEM). Go remove your light.

**Profile 2 (Integrated Prongs):**
1. Print the end piece and handle. Print the grip collar too (Profile 3) only if you need it.
2. Insert the handle's tabs into the slots on the underside of the end piece. Epoxy here is optional — mine ran fine unglued. If gluing, cure overnight.
3. Drop the end piece into the grip collar (printed or OEM). Go remove your light.

**Profile 3 (Grip Collar):**
1. Print the grip collar. Drop your end piece in and go.

## Compatibility

Lights: Hayward ColorLogic 160, ColorLogic 320
Wall fittings: Hayward SP0537, SP0538 (1.5" female pipe thread)
Replaces: Hayward SP0536CTOOL

## Notes

The grip collar has its own set of prongs and could probably benefit from the same separated-prong treatment, but mine didn't break, so I haven't designed that variant yet. Yes, I designed a whole replacement collar for a part that was working fine, and no, I will not be explaining the separated-prong variant I didn't make for the collar I didn't need. Eventually, maybe.

Pool equipment involves water-tight seals and electrical components. Verify fit before relying on this for anything permanent, and use at your own risk. If a prong shears mid-twist you'll know which profile you should have picked.

## Source & Documentation

OpenSCAD source, photos, and full documentation: [github.com/billism1/3d-print-hayward-accent-light-installation-tool](https://github.com/billism1/3d-print-hayward-accent-light-installation-tool)

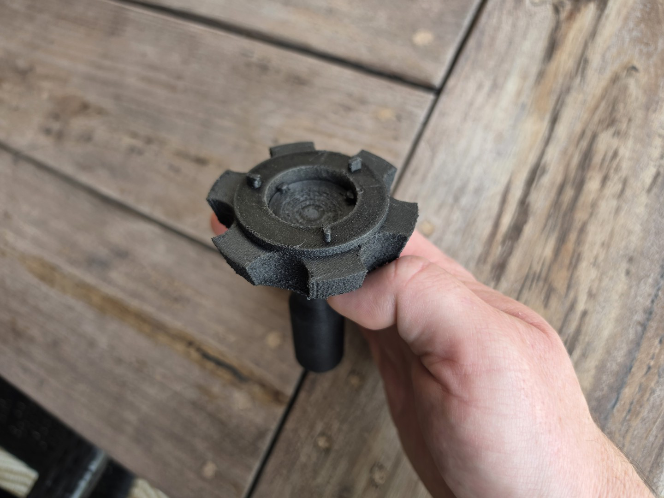
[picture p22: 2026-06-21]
images/hand-tool-integrated-prongs-in-collar-grip-all-printed.jpg

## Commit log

2026-04-11 Add OpenSCAD prompt and implementation for Hayward ColorLogic accent light installation tool
    [hayward-accent-light-installation-tool.scad]
2026-04-11 Update parameters for Hayward ColorLogic accent light installation tool: adjust disc thickness, prong height, and arc length; increase quality resolution.
    [hayward-accent-light-installation-tool.scad, hayward-accent-light-installation-tool_end.stl]
2026-04-11 Refactor Hayward ColorLogic accent light installation tool: update disc thickness, add handle and tab parameters, and implement end piece and handle modules for improved assembly.
    [hayward-accent-light-installation-tool.scad]
2026-04-11 Add handle module and render toggles for Hayward ColorLogic accent light installation tool
    [hayward-accent-light-installation-tool.scad, hayward-accent-light-installation-tool_end.stl, hayward-accent-light-installation-tool_handle.stl]
2026-04-11 Refactor handle module in Hayward ColorLogic accent light installation tool: adjust handle diameter, add neck parameters, and modify handle geometry for improved design.
    [hayward-accent-light-installation-tool.scad]
2026-04-11 Add 3D model files for Hayward ColorLogic accent light installation tool
    [hayward-accent-light-installation-tool.3mf, hayward-accent-light-installation-tool_end.stl, hayward-accent-light-installation-tool_handle.stl]
2026-04-11 Refactor end piece module in Hayward ColorLogic accent light installation tool: add concave dish cutout and adjust prong height calculation.
    [hayward-accent-light-installation-tool.scad, hayward-accent-light-installation-tool_end.stl]
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2026-04-11 Update disc diameter and enable handle rendering in accent light installation tool
    [hayward-accent-light-installation-tool.scad]
2026-04-11 Adjust prong arc length and implement lens shape for improved prong design in accent light installation tool
    [hayward-accent-light-installation-tool.scad]
2026-04-11 Adjust dish radius calculation in dish cutout module for improved fit of the end piece
    [hayward-accent-light-installation-tool.scad, hayward-accent-light-installation-tool_end.stl]
2026-04-11 Add new prong and handle modules to the Hayward ColorLogic accent light installation tool
    [hayward-accent-light-installation-tool_prongs-separated.scad]
2026-04-11 Enhance prong design by adding insertion depth and clearance parameters, and implement prong slots for improved fitting and printing.
    [hayward-accent-light-installation-tool_prongs-separated.scad]
2026-04-11 Reposition individual prongs for improved printing layout and add gap between prong and disc edge
    [hayward-accent-light-installation-tool_prongs-separated.scad]
2026-04-11 Update rendering options and improve dish cutout calculation for accent light tool
    [hayward-accent-light-installation-tool.3mf, hayward-accent-light-installation-tool.scad, hayward-accent-light-installation-tool_end.stl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]
2026-04-11 Enable rendering of handle and prongs in accent light installation tool, and reduce quality factor for improved performance
    [hayward-accent-light-installation-tool.scad, hayward-accent-light-installation-tool_prongs-separated.scad]
2026-04-11 Add handle short STL file and adjust handle length parameter to 50mm
    [hayward-accent-light-installation-tool.scad, hayward-accent-light-installation-tool_handle_short.stl]
2026-04-11 Update 3MF file for accent light installation tool with improved design features
    [hayward-accent-light-installation-tool.3mf]
2026-04-11 Update 3MF file for accent light installation tool with new design modifications
    [hayward-accent-light-installation-tool.3mf]
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2026-04-11 Update grip collar height and add taper for improved fit and support
    [hayward-accent-light-installation-tool.scad]
2026-04-11 Add collar prong parameters and adjust tab clearance for improved fit
    [hayward-accent-light-installation-tool.scad, hayward-accent-light-installation-tool_handle.stl, hayward-accent-light-installation-tool_handle_short.stl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]
2026-04-11 Update 3MF file for accent light installation tool with latest design changes
    [hayward-accent-light-installation-tool.3mf]
2026-04-12 Adjust tab clearance for improved press-fit tolerance in handle module
    [hayward-accent-light-installation-tool.scad]
2026-04-12 Update STL files for accent light installation tool with latest design modifications
    [hayward-accent-light-installation-tool_end_with_prong_slots.stl, hayward-accent-light-installation-tool_handle.stl, hayward-accent-light-installation-tool_hand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]
2026-04-12 Update STL file for accent light installation tool with latest design modifications
    [hayward-accent-light-installation-tool_end.stl]
2026-04-12 Update 3MF file for accent light installation tool with latest design modifications
    [hayward-accent-light-installation-tool.3mf]
2026-04-12 Refactor handle rendering logic and adjust handle length for improved design integration
    [hayward-accent-light-installation-tool.scad]
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2026-04-12 Update rendering settings for end piece and increase resolution for improved quality
    [hayward-accent-light-installation-tool.scad, hayward-accent-light-installation-tool_one_peice.stl]
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2026-04-12 Add collar lip parameters and implement retention lip in grip collar module
    [hayward-accent-light-installation-tool.scad]
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2026-04-12 Refine grip collar parameters and add base thickness for improved design clarity
    [hayward-accent-light-installation-tool.scad]
2026-04-12 Enhance collar prong design with new length parameter and adjust arc positioning for improved fit
    [hayward-accent-light-installation-tool.scad]
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2026-04-12 Adjust collar prong outer diameter and reposition arc for improved design integrity
    [hayward-accent-light-installation-tool.scad]
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
